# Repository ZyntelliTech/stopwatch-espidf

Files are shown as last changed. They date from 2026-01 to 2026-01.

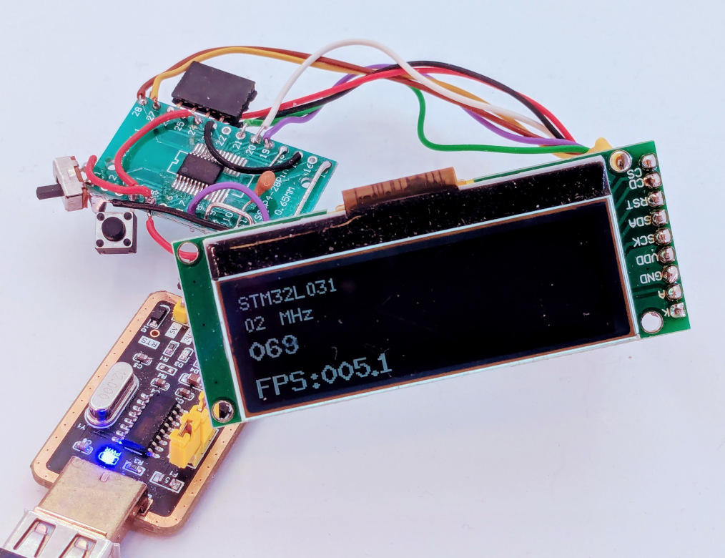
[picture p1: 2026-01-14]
Firmware/components/u8g2/sys/arm/stm32l031x4/u8g2_dma_spi_2mhz/stm32l031_wired.jpg

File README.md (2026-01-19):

# Stopwatch ESP-IDF Project

This project implements a stopwatch using ESP-IDF on an ESP32 microcontroller with an OLED display.
## Hardware Architecture
The ESP32-S3 GPIO pins have been assigned as follows: 

GPIO12 ------> SCL <br>
GPIO11 ------> SDA <br> 
GPIO10 ------> CS <br>
GPIO9  ------> DC<br>
GPIO8  ------> RES<br>

GPIO5  ------> left button: Start/Stop <br>
GPIOP6 ------> middle button: lapping/page navigation <br>
GPIO7  ------> right button: reset<br>

You can check the details in the schematic.

### How to order prototypes in JLCPCB
- Go to jlcpcb.com
- Click "Order now"
- Click "Add Gerber file" and upload /Hardware/Gerber_xxxxxxx.zip file
- Select the PCB Qty
- Enable the PCB Assembly
- Choose the Standard and Top Side assembly
- Click the NEXT button in the right panel. You will go to the next page
- Add the BOM and CPL(Pick-and-Place) files from hardware directory
- You can check the component stocks in the list
- In the Component Placements, you can check the assembled board.
- You can check the price in the Quote & Order page and save to cart

## Firmware Development

### Prerequisites

- [Visual Studio Code](https://code.visualstudio.com/)
- ESP32 development board (e.g., ESP32-S3)
- USB cable for flashing

### Installing ESP-IDF in VS Code

Follow these steps to set up the ESP-IDF development environment in Visual Studio Code. [Refer to this link.](https://www.youtube.com/watch?v=D0fRc4XHBNk) 

### 1. Install Visual Studio Code
If you haven't already, download and install VS Code from the official website.

### 2. Install the ESP-IDF Extension
1. Open VS Code.
2. Go to the Extensions view by clicking on the Extensions icon in the Activity Bar on the side of the window (or press `Ctrl+Shift+X`).
3. Search for "ESP-IDF".
4. Find the extension published by "Espressif Systems" and click "Install".

### 3. Open the Project
1. Open VS Code.
2. Select "File" > "Open Folder" and navigate to the `stopwatch-espidf/Firmware` directory.

### 4. Build and Flash the Project
1. In VS Code, open the Command Palette (`Ctrl+Shift+P`).
2. Type "ESP-IDF: Open ESP-IDF Terminal" and click it
3. Run "idf.py build".
4. Connect your ESP32 board via USB.
5. Run "idf.py flash monitor" to flash the firmware.
6. Optionally, run "idf.py -p COM[X] flash monitor" if the COM port is not automatically selected

## Project Structure

- `Firmware/`: Contains the ESP-IDF project files.
- `Firmware/main/`: Source code for the stopwatch application.
- `Firmware/components/`: Additional components like u8g2 for OLED display.
- `images/`: Project images like testing board diagram

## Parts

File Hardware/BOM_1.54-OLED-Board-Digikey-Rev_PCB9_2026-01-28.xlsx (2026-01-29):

No. | Quantity | Comment | Designator | Footprint | Value | Manufacturer Part | Manufacturer | Supplier Part | Supplier | LCSC Stock | LCSC Price | JLCPCB Stock | JLCPCB Price
1 | 1 | 2.2uF | C1 | C0201 | 2.2uF | CL03A225MP3CRNC | SAMSUNG(三星) | C318539 | LCSC |  |  | 319386 | 0.0011
2 | 8 | 10uF | C2,C4,C6,C7,C11,C12,C14,C18 | C0402 | 10uF | CL05A106MP5NUNC | SAMSUNG(三星) | C315248 | LCSC |  |  | 5447049 | 0.0013
3 | 6 | 100nF | C3,C5,C9,C10,C13,C16 | C0201 | 100nF | GRM033R61A104KE15D | muRata(村田) | C76934 | LCSC |  |  | 5065496 | 0.0002
4 | 1 | 1uF | C8 | C0201 | 1uF | HGC0201R5105K100NTCJ | Chinocera(华瓷) | C7432760 | LCSC |  |  | 51579 | 0.0015
5 | 1 | 22pF | C15 | C0201 | 22pF | CC0201JRNPO8BN220 | YAGEO(国巨) | C526934 | LCSC |  |  | 7062 | 0.0002
6 | 2 | 100nF | C17,C20 | C0201 | 100nF | CC0201KRX5R8BB104 | YAGEO(国巨) | C718252 | LCSC |  |  | 479402 | 0.0006
7 | 2 | 4.7uF | C19,C21 | C0603 | 4.7uF | GRM188R61E475KE11D | muRata(村田) | C90057 | LCSC |  |  | 348010 | 0.0037
8 | 1 | A1251WV-2P | CN1 | CONN-TH_2P-P1.25_A1251WV-2P |  | A1251WV-2P | CJT(长江连接器) | C5333427 | LCSC |  |  | 16958 | 0.0073
9 | 1 | LESD8LH5.0CT5G | D1 | SOD-882_L1.0-W0.6-BI |  | LESD8LH5.0CT5G | LRC(乐山无线电) | C172420 | LCSC |  |  | 13267 | 0.0023
10 | 2 | 1N5819WS | D2,D3 | SOD-323_L1.8-W1.3-LS2.5-RD |  | 1N5819WS | Hottech(合科泰) | C191023 | LCSC |  |  | 3408966 | 0.0012
11 | 1 | PM254V-11-06-H85 | H1 | HDR-TH_6P-P2.54-V-F |  | PM254V-11-06-H85 | XFCN(兴飞) | C2832269 | LCSC |  |  | 34883 | 0.0106
12 | 1 | 10uH | L1 | IND-SMD_L2.5-W2.0_MHCD252012B-2R2M-A8L | 10uH | DFE252012F-100M=P2 | muRata(村田) | C703141 | LCSC |  |  | 6823 | 0.0217
13 | 1 | HC-FPC-05-09-24RLTAG | P1 | FPC-SMD_24P-P0.50_HC-FPC-05-09-24RLTAG |  | HC-FPC-05-09-24RLTAG | HCTL(华灿天禄) | C5213757 | LCSC |  |  | 39879 | 0.0234
14 | 1 | AO3401A | Q1 | SOT-23_L2.9-W1.3-P1.90-LS2.4-BR |  | AO3401A | UMW(友台半导体) | C347476 | LCSC |  |  | 966091 | 0.0044
15 | 1 | SS8550W | Q2 | SOT-323-3_L2.0-W1.3-P1.30-LS2.3-BR |  | SS8550W | TWGMC(迪嘉) | C5189253 | LCSC |  |  | 17081 | 0.0028
16 | 2 | 5.1kΩ | R1,R2 | R0201 | 5.1kΩ | 0201WMF5101TEE | UNI-ROYAL(厚声) | C270344 | LCSC |  |  | 295343 | 0.0002
17 | 3 | 100kΩ | R3,R13,R16 | R0201 | 100kΩ | 0201WMF1003TEE | UNI-ROYAL(厚声) | C270364 | LCSC |  |  | 2234534 | 0.0002
18 | 4 | 10kΩ | R4,R9,R10,R12 | R0201 | 10kΩ | 0201WMF1002TEE | UNI-ROYAL(厚声) | C473048 | LCSC |  |  | 1248891 | 0.0002
19 | 1 | 1kΩ | R5 | R0402 | 1kΩ | RMC04021K5%N | Tyohm(幸亚电阻) | C270121 | LCSC |  |  | 4188 | 0.0003
20 | 1 | 2kΩ | R6 | R0201 | 2kΩ | 0201WMF2001TEE | UNI-ROYAL(厚声) | C270358 | LCSC |  |  | 728999 | 0.0002
21 | 2 | 470kΩ | R7,R8 | R0201 | 470kΩ | 0201WMF4703TEE | UNI-ROYAL(厚声) | C473560 | LCSC |  |  | 2133 | 0.0002
22 | 1 | 470Ω | R11 | R0201 | 470Ω | 0201WMF4700TEE | UNI-ROYAL(厚声) | C473464 | LCSC |  |  | 91499 | 0.0002
23 | 1 | 887kΩ | R14 | R0201 | 887kΩ | RC0201FR-07887KL | YAGEO(国巨) | C474853 | LCSC |  |  | 4670 | 0.0002
24 | 3 | 4.7kΩ | R15,R17,R18 | R0201 | 4.7kΩ | 0201WMF4701TEE | UNI-ROYAL(厚声) | C270346 | LCSC |  |  | 345024 | 0.0002
25 | 1 | 910kΩ | R19 | R0201 | 910kΩ | RC0201FR-07910KL | YAGEO(国巨) | C295818 | LCSC |  |  | 7664 | 0.0002
26 | 3 | HX-3x6x3.5-CA-0.6-2.5N | SW1,SW2,SW3 | SW-SMD_HX-3X6X3.5-CA-0.6-2.5N |  | HX-3x6x3.5-CA-0.6-2.5N | hanxia(韩下) | C49234146 | LCSC |  |  | 18106 | 0.0033
27 | 1 | 2.4GHz | U1 | BULETM-SMD_ESP32-S3-MINI-1-N8 | 2.4GHz | ESP32-S3-MINI-1-N8 | ESPRESSIF(乐鑫) | C2913206 | LCSC |  |  | 10861 | 0.6671
28 | 1 | SPX3819M5-L-3-3 | U2 | SOT-23-5_L3.0-W1.6-P0.95-LS2.8-BR |  | SPX3819M5-L-3-3 | TECH PUBLIC(台舟) | C20617301 | LCSC |  |  | 42998 | 0.0151
29 | 1 | GT-USB-7040C | U3 | USB-C-SMD_GT-USB-7040C |  | GT-USB-7040C | G-Switch(品赞) | C5447091 | LCSC |  |  | 4656 | 0.0411
30 | 1 | XL-1005UOC | U4 | LED0402-RD_ORANGE |  | XL-1005UOC | XINGLIGHT(成兴光) | C965791 | LCSC |  |  | 54064 | 0.002
31 | 1 | TP4054 | U5 | TSOT-23-5_L2.9-W1.6-P0.95-LS2.8-BR |  | TP4054 | UMW(友台半导体) | C668215 | LCSC |  |  | 162439 | 0.0048
33 | 1 | W25Q128JVPIQ | U7 | WSON-8_L6.0-W5.0-P1.27-BL-EP |  | W25Q128JVPIQ | Winbond(华邦) | C190862 | LCSC |  |  | 8996 | 0.3958
34 | 1 | AP3012KTR-G1 | U8 | TSOT-23-5_L2.9-W1.6-P0.95-LS2.8-BL |  | AP3012KTR-G1 | DIODES(美台) | C102618 | LCSC |  |  | 4829 | 0.0155

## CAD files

Firmware/components/u8g2/sys/arduino/u8g2_full_buffer/SwitchBox/board.dxf
60
40
52
8
24
80
30
32
25
100
190
4
12
6
14

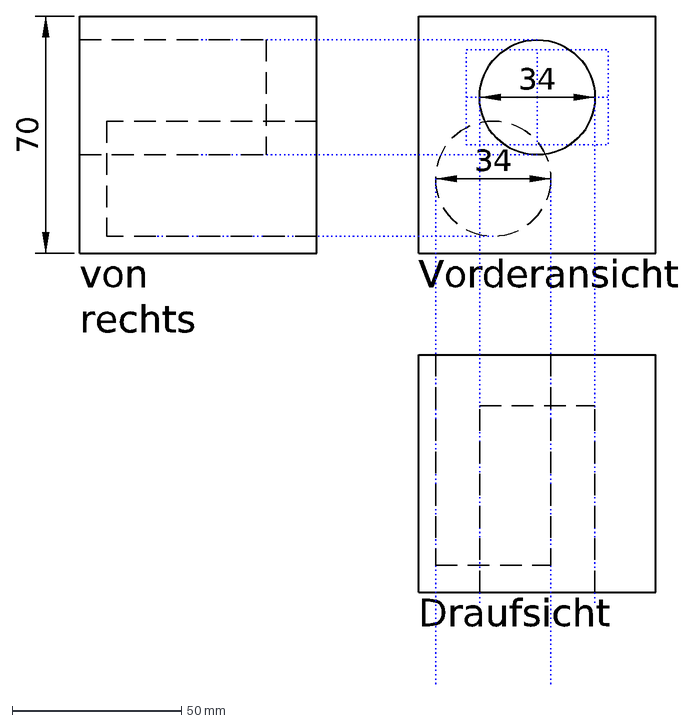
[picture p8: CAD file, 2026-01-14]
Firmware/components/u8g2/sys/arm/stm32l031x6/clock_cube.dxf
Draufsicht
Vorderansicht
von rechts
70
34

Firmware/components/u8g2/sys/arm/stm32l031x6/clock.dxf
65
32
28
16
Draufsicht
Vorderansicht
von unten
von rechts
von links
14
6
45
60
30
20
8
35
75
55
10
12

Firmware/components/u8g2/sys/arm/stm32l031x6/clock_2.dxf
65
Draufsicht
Vorderansicht
von unten
von rechts
von links
14
30
32
35
75
55
10
12
16
11
22
34
28
29
18
93
19
43
15
68
60
57
150
Holzbohrer: 2.5, 8, 10, 12, 16, 32mm
8
7
6
2.5mm

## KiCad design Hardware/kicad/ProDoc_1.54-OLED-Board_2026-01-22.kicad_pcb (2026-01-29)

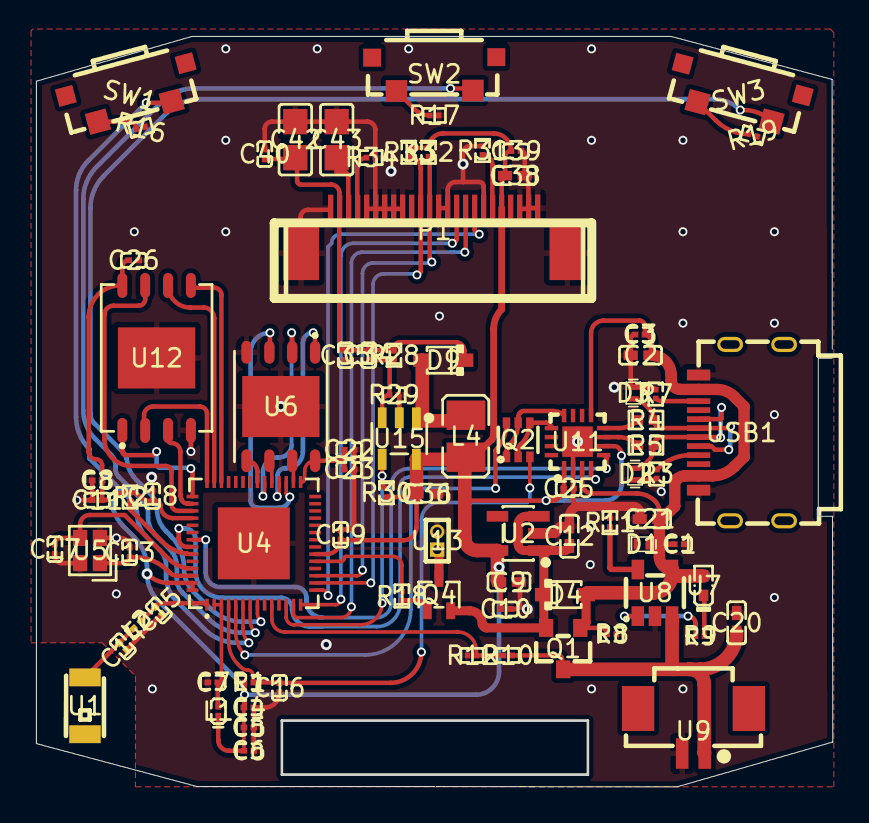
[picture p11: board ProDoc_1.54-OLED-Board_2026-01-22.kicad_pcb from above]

Board: 2 copper layers, 44.2 x 41.7 mm, 83 parts (0 on the bottom side), 61 nets.

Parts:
C1: 2.2uF; C0201
C2, C9, C12, C20, C21, C36, C38: 10uF; C0402
C3, C4, C6, C7, C8, C10, C11, C16, C18, C19, C22, C25, C26, C35, C39, C40: 100nF; C0201
C5, C23: 1uF; C0201
C13, C17: 15pF; C0201
C14: 1.8pF; C0201
C15: 1.2pF; C0201
C34: 22pF; C0201
C42, C43: 10uF; C0805
D1, D2, D3: LESD8LH5.0CT5G; SOD-882_L1.0-W0.6-BI
D4, D9: 1N5819WS_C191023; SOD-323_L1.8-W1.3-LS2.5-RD
L1: 2nH; L0201-RD
L2: 2.4nH; L0201
L4: 10uH; L1008
P1: FPC 0.5MM 24P Pull type H2.0mm Pick up; FPC-SMD_24P-L17.5-W5.4-P0.50
Q1: AO3401A_C347476; SOT-23_L2.9-W1.3-P1.90-LS2.4-BR
Q2: UMH3N; SC-70-6_L2.2-W1.3-P0.65-LS2.1-BR
Q4: SS8550W; SOT-323-3_L2.0-W1.3-P1.30-LS2.3-BR
R1, R2, R16, R17, R19: 10kΩ; R0201
R3, R7: 5.1kΩ; R0201
R4, R5: 0Ω; R0402
R8, R29, R30: 100kΩ; R0201
R9: 1kΩ; R0201
R10, R12: 470kΩ; R0201
R11: 2kΩ; R0201
R18: 470Ω; R0201
R28: 887kΩ; R0201
R31, R32, R33: 4.7kΩ; R0201
R34: 910kΩ; R0201
SW1, SW2, SW3: TS36CA-0.6 250gf 031; SW-SMD_SHOU_TS36CA-0.6
U1: ANT3216LL00R2400A; ANT-SMD_L3.2-W1.6
U2: SPX3819M5-L-3-3; SOT-23-5_L3.0-W1.6-P0.95-LS2.8-BR
U4: ESP32-S3R8; QFN-56_L7.0-W7.0-P0.40-TL-EP4.0
U5: 40MHz; CRYSTAL-SMD_4P-L2.0-W1.6-BL
U6: W25Q128JVPIQ; WSON-8_L6.0-W5.0-P1.27-BL-EP
U7: XL-1005UOC; LED0402-RD_ORANGE
U8: TP4054_C668215; TSOT-23-5_L2.9-W1.6-P0.95-LS2.8-BR
U9: ZX-MX1.25-2PWT; CONN-SMD_2P-P1.25_MEGASTAR_ZX-MX1.25-2PWT
U11: CH343P; TQFN-16_L3.0-W3.0-P0.50-BL-EP1.7
U12: W25N01GVZEIG; WSON-8_L8.0-W6.10-P1.27-BL-EP
U13: HX PZ1.0-1x2P ZZ; HDR-TH_2P-P1.00-V-M
U15: TPS61040DBVR; SOT-23-5_L3.0-W1.7-P0.95-LS2.8-BL
USB1: HYCW412-USBC16-065B; USB-C-SMD_HYCW412-USBC16-065B

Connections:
5V: C1.1, C2.2, C3.2, C21.2, D1.1, D4.2, Q1.1, R8.1, U7.2, U8.4, U11.3, U11.9, USB1.A4B9, USB1.B4A9
12V: C34.2, C35.2, C40.2, C42.2, D9.1, P1.23, R28.2
$1N9431: C15.2, L2.2, U4.1
$1N9432: C7.2, L1.2, U4.2, U4.3
$1N9438: C13.1, U4.54, U5.1
$1N9473: C17.2, U4.53, U5.3
$1N9512: R9.1, U7.1
$1N9513: R9.2, U8.1
$1N9514: R11.1, U8.5
$1N9533: R16.1, SW1.1
$1N9534: R17.1, SW2.1
$1N9535: R19.1, SW3.1
$1N9548: Q4.1, R18.2
$1N9549: Q4.3, U13.1
$1N9587: C14.2, L2.1, U1.2
$1N9591: R7.2, USB1.B5
$1N9592: R3.1, USB1.A5
$1N9604: P1.6, R31.2
$1N9614: D9.2, L4.2, U15.1
$1N9616: C34.1, R28.1, R29.2, U15.3
$1N9620: P1.21, R34.2
$1N9621: C43.2, P1.22
+3V3: C4.2, C5.2, C6.2, C8.2, C9.2, C10.2, C11.2, C18.2, C19.2, C25.2, C26.2, C36.2, C38.1, C39.1, L1.1, L4.1, P1.5, R1.2, R2.2, R30.2, R32.1, R33.1, U2.5, U4.20, U4.46, U4.55, U4.56, U11.1, U11.6, U12.8, U15.5
BAT_ADC: R10.1, R12.2, U4.10
BUZZER: R18.1, U4.19
CHIP_EN: C16.2, Q2.3, R1.1, U4.4
CLK: P1.13, R32.2, U4.17
CS: P1.8, U4.15
D+: R5.1, U11.7
D-: R4.1, U11.8
DC: P1.10, U4.14
DIN: P1.14, R33.2, U4.16
DTR: Q2.1, Q2.5, U11.12
EN: R30.1, U4.12, U15.4
FCLK: U4.41, U12.6
FCS: U4.43, U12.1
FDI: U4.40, U12.5
FDO: U4.42, U12.2
FHOLD: U4.45, U12.7
FWP: U4.44, U12.3
GND: C1.2, C2.1, C3.1, C4.1, C5.1, C6.1, C7.1, C8.1, C9.1, C10.1, C11.1, C12.1, C13.2, C14.1, C15.1, C16.1, C17.1, C18.1, C19.1, C20.1, C21.1, C22.1, C23.1, C25.1, C26.1, C35.1, C36.1, C38.2, C39.2, C40.1, C42.1, C43.1, D1.2, D2.2, D3.1, P1.1, P1.2, P1.3, P1.7, P1.11, P1.12, P1.16, P1.17, P1.18, P1.19, P1.20, P1.24, P1.25, P1.26, R3.2, R7.1, R8.2, R11.2, R12.1, R16.2, R17.2, R19.2, R29.1, R31.1, R34.1, U2.2, U4.57, U5.2, U5.4, U6.4, U6.9, U8.2, U9.2, U11.2, U11.17, U12.4, U12.9, U13.2, U15.2, USB1.A1B12, USB1.B1A12
IO0: Q2.6, U4.5
IO45: R2.1, U4.51
KEY1: SW1.2, U4.6
KEY2: SW2.2, U4.7
KEY3: SW3.2, U4.8
RES: P1.9, U4.13
RTS: Q2.2, Q2.4, U11.13
SPICLK: U4.33, U6.6
SPICS0: U4.32, U6.1
SPID: U4.35, U6.5
SPIHD: U4.30, U6.7
SPIQ: U4.34, U6.2
SPIWP: U4.31, U6.3
U0RXD: U4.50, U11.4
U0TXD: U4.49, U11.5
USB+: D2.1, R5.2, USB1.A6, USB1.B6
USB-: D3.2, R4.2, USB1.A7, USB1.B7
VBAT: C20.2, Q1.3, R10.2, U8.3, U9.1
VDD_SPI: C22.2, C23.2, U4.29, U6.8
VSYS: C12.2, D4.1, Q1.2, Q4.2, U2.1, U2.3

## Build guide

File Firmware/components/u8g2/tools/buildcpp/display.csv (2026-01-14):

# 1. device name
# 2. pinset
# 3. constructor name w/o prefix
u8x8_d_ssd1306_128x64_noname | 4WSWSPI | SSD1306_128X64_4W_SW_SPI
u8x8_d_ssd1306_128x64_noname | 4WHWSPI | SSD1306_128X64_4W_HW_SPI
u8x8_d_ssd1306_128x64_noname | 3WSWSPI | SSD1306_128X64_3W_SW_SPI
u8x8_d_ssd1306_128x64_noname | SSDSWI2C | SSD1306_128X64_SW_I2C
u8x8_d_ssd1306_128x64_noname | 6800 | SSD1306_128X64_6800
u8x8_d_ssd1306_128x64_noname | 8080 | SSD1306_128X64_8080

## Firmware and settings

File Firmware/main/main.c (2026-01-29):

#include <stdio.h>
#include <string.h>
#include "freertos/FreeRTOS.h"
#include "freertos/task.h"
#include "sdkconfig.h"
#include "esp_log.h"
#include "rtc_timer.h"
#include "oled.h"
#include "stopwatch.h"
#include "driver/gpio.h"

#define DEBOUNCE_MS  10
typedef struct {
    char name[32];
    char type[32];
    char lane_count[2];
    char watch_number[2];
} player_t;

player_t player;

typedef enum {
    STOPWATCH_PAGE = 0,
    SWIMMING_PAGE,
    CONFIRM_PAGE,
    HEADTIMER_PAGE
} page_state_t;

static const char *TAG = "main";
static char time_buffer[16] = {0};
uint8_t page_index = STOPWATCH_PAGE;

#define BTN_START_STOP   GPIO_NUM_5
#define BTN_RECALL       GPIO_NUM_6
#define BTN_LAP_RESET    GPIO_NUM_7

static void buttons_init(void)
{
    gpio_config_t io_conf = {
        .pin_bit_mask =
            (1ULL << BTN_START_STOP) |
            (1ULL << BTN_RECALL) |
            (1ULL << BTN_LAP_RESET),
        .mode = GPIO_MODE_INPUT,
        .pull_up_en = GPIO_PULLUP_ENABLE,
        .pull_down_en = GPIO_PULLDOWN_DISABLE,
        .intr_type = GPIO_INTR_DISABLE
    };
    gpio_config(&io_conf);
}

/* 1-second periodic task */
static void one_second_task(void *arg)
{
    TickType_t last_wake_time = xTaskGetTickCount();

    while (1)
    {
        /* Runs exactly every 1 second */
        vTaskDelayUntil(&last_wake_time, pdMS_TO_TICKS(1000));

        rtc_get_time(time_buffer, sizeof(time_buffer));
    }
}

void app_main(void)
{
    uint32_t last_state = 0xFFFFFFFF;
    uint32_t stable_state = last_state;
    bool stopwatch_running = false;

    ESP_LOGI(TAG, "Initializing OLED display");
    oled_init();
    buttons_init();

    rtc_set_time(2026, 1, 6, 15, 0, 0);

    ESP_LOGI(TAG, "All done!");
    
    char buf[16];   // ✅ RAM buffer
    char lap_buf[16];
    char split_buf[16];
    char lap_count_str[4];
    uint8_t lap_count = 0;
    
    memset(buf, '0', sizeof(buf));
    memset(lap_buf, '0', sizeof(lap_buf));
    memset(split_buf, '0', sizeof(split_buf));
    memset(lap_count_str, '0', sizeof(lap_count_str));

    while (1)
    {  
        uint32_t state =
            (gpio_get_level(BTN_START_STOP) << 0) |
            (gpio_get_level(BTN_RECALL)     << 1) |
            (gpio_get_level(BTN_LAP_RESET)  << 2);
        
        if (state != last_state) {
            vTaskDelay(pdMS_TO_TICKS(DEBOUNCE_MS));
            last_state = state;
            continue;
        }
        if (state != stable_state) {
            stable_state = state;

            //Active Low buttons
            if (!(state & (1 << 0))) {  // START/STOP - Right Button
                if ((page_index != CONFIRM_PAGE)){
                    if(get_stopwatch_state() == 0) {
                        stopwatch_start();
                    } else {
                        stopwatch_stop();
                    }
                } else {
                    page_index = SWIMMING_PAGE;
                    strcpy(player.name, "");
                    strcpy(player.type, "FREESTYLE");  
                    strcpy(player.lane_count, "4");
                    strcpy(player.watch_number, "1");     
                }
            }
            if (!(state & (1 << 1))) {  // LAP / PAGE SWITCH - Middle Button
                if (get_stopwatch_state()) {
                    if ((page_index == STOPWATCH_PAGE) && stopwatch_lap()) {
                        lap_entry_t lap;
                        uint8_t idx = stopwatch_get_lap_count() - 1;
                        stopwatch_get_lap(idx, &lap);
                        stopwatch_get_lap_str(idx, lap_buf, sizeof(lap_buf));
                        stopwatch_get_split_str(idx, split_buf, sizeof(split_buf));
                        snprintf(lap_count_str, sizeof(lap_count_str), "%02u", idx + 1);
                    }

                } else {
                    if (page_index == SWIMMING_PAGE) {
                        page_index = STOPWATCH_PAGE;
                    }
                    else if (page_index == STOPWATCH_PAGE) {
                        page_index = SWIMMING_PAGE;
                    }
                }
            }
            if (!(state & (1 << 2))) {   // RESET - Left Button
                if (stopwatch_is_initialized()){
                    if (page_index == SWIMMING_PAGE) {
                        page_index = CONFIRM_PAGE;
                    } else if (page_index == CONFIRM_PAGE) {
                        page_index = SWIMMING_PAGE;
                        strcpy(player.name, "JOHN DOE");
                        strcpy(player.type, "FREESTYLE");  
                        strcpy(player.lane_count, "4");
                        strcpy(player.watch_number, "1");            
                    }
                } else {
                    if ((get_stopwatch_state() == 0)) {
                        stopwatch_reset();
                        memset(buf, '0', sizeof(buf));
                        memset(lap_buf, '0', sizeof(lap_buf));
                        memset(split_buf, '0', sizeof(split_buf));
                        memset(lap_count_str, '0', sizeof(lap_count_str));
                    }
                }
                
            }
        }

        stopwatch_get_str_10ms(buf, sizeof(buf));

        switch (page_index)
        {
            case STOPWATCH_PAGE:
            oled_draw_stopwatch(buf, lap_buf, split_buf, lap_count_str);
            break;
        case SWIMMING_PAGE:
            oled_draw_swimming_watch(buf, player.name, player.type, player.lane_count, player.watch_number, true);
            break;
        case HEADTIMER_PAGE:
            oled_draw_headtimer_watch(buf, true);
            break;
        case CONFIRM_PAGE:
            oled_draw_confirm_watch();
            break;
        default:
            break;
        }
        vTaskDelay(pdMS_TO_TICKS(1));
    }
}

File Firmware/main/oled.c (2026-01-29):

#include "oled.h"
#include <driver/gpio.h>
#include <driver/spi_master.h>
#include <esp_log.h>
#include <freertos/FreeRTOS.h>
#include <freertos/task.h>
#include <stdio.h>
#include <string.h>
#include <u8g2.h>
#include "u8g2_esp32_hal.h"

// CLK - GPIO12
#define PIN_CLK 12

// MOSI - GPIO 11
#define PIN_MOSI 11

// RESET - GPIO 8
#define PIN_RESET 8

// DC - GPIO 9
#define PIN_DC 9

// CS - GPIO 10
#define PIN_CS 10

static const char *TAG = "OLED";

static u8g2_t u8g2;

/* Stopwatch Assets*/
static const uint8_t image_battery_full_bits[] = {0x00,0x00,0x00,0xf0,0xff,0x7f,0x08,0x00,0x80,0x68,0xdb,0xb6,0x6e,0xdb,0xb6,0x61,0xdb,0xb6,0x61,0xdb,0xb6,0x61,0xdb,0xb6,0x61,0xdb,0xb6,0x61,0xdb,0xb6,0x6e,0xdb,0xb6,0x68,0xdb,0xb6,0x08,0x00,0x80,0xf0,0xff,0x7f,0x00,0x00,0x00,0x00,0x00,0x00};
static const uint8_t image_battery_17_bits[] = {0x00,0x00,0x00,0xf0,0xff,0x7f,0x08,0x00,0x80,0x08,0x00,0xb0,0x0e,0x00,0xb0,0x01,0x00,0xb0,0x01,0x00,0xb0,0x01,0x00,0xb0,0x01,0x00,0xb0,0x01,0x00,0xb0,0x0e,0x00,0xb0,0x08,0x00,0xb0,0x08,0x00,0x80,0xf0,0xff,0x7f,0x00,0x00,0x00,0x00,0x00,0x00};
static const uint8_t image_battery_33_bits[] = {0x00,0x00,0x00,0xf0,0xff,0x7f,0x08,0x00,0x80,0x08,0x00,0xb6,0x0e,0x00,0xb6,0x01,0x00,0xb6,0x01,0x00,0xb6,0x01,0x00,0xb6,0x01,0x00,0xb6,0x01,0x00,0xb6,0x0e,0x00,0xb6,0x08,0x00,0xb6,0x08,0x00,0x80,0xf0,0xff,0x7f,0x00,0x00,0x00,0x00,0x00,0x00};
static const uint8_t image_battery_50_bits[] = {0x00,0x00,0x00,0xf0,0xff,0x7f,0x08,0x00,0x80,0x08,0xc0,0xb6,0x0e,0xc0,0xb6,0x01,0xc0,0xb6,0x01,0xc0,0xb6,0x01,0xc0,0xb6,0x01,0xc0,0xb6,0x01,0xc0,0xb6,0x0e,0xc0,0xb6,0x08,0xc0,0xb6,0x08,0x00,0x80,0xf0,0xff,0x7f,0x00,0x00,0x00,0x00,0x00,0x00};
static const uint8_t image_battery_67_bits[] = {0x00,0x00,0x00,0xf0,0xff,0x7f,0x08,0x00,0x80,0x08,0xd8,0xb6,0x0e,0xd8,0xb6,0x01,0xd8,0xb6,0x01,0xd8,0xb6,0x01,0xd8,0xb6,0x01,0xd8,0xb6,0x01,0xd8,0xb6,0x0e,0xd8,0xb6,0x08,0xd8,0xb6,0x08,0x00,0x80,0xf0,0xff,0x7f,0x00,0x00,0x00,0x00,0x00,0x00};
static const uint8_t image_battery_83_bits[] = {0x00,0x00,0x00,0xf0,0xff,0x7f,0x08,0x00,0x80,0x08,0xdb,0xb6,0x0e,0xdb,0xb6,0x01,0xdb,0xb6,0x01,0xdb,0xb6,0x01,0xdb,0xb6,0x01,0xdb,0xb6,0x01,0xdb,0xb6,0x0e,0xdb,0xb6,0x08,0xdb,0xb6,0x08,0x00,0x80,0xf0,0xff,0x7f,0x00,0x00,0x00,0x00,0x00,0x00};

static const uint8_t image_chrono_minute_colon_bits[] = {0x03,0x03,0x00,0x00,0x00,0x00,0x00,0x00,0x00,0x03,0x03};
static const uint8_t image_chrono_second_point_bits[] = {0x03,0x03};
static const uint8_t image_lap_string_bits[] = {0x03,0x30,0xfc,0x00,0x03,0x78,0xfc,0x01,0x03,0x78,0x0c,0x03,0x03,0xcc,0x0c,0x03,0x03,0xcc,0xfc,0x01,0x03,0x86,0xfd,0x00,0x03,0xfe,0x0d,0x00,0x03,0xfe,0x0d,0x00,0x03,0x86,0x0d,0x00,0xff,0x86,0x0d,0x00,0xff,0x86,0x0d,0x00};
static const uint8_t image_split_hour_colon_bits[] = {0x03,0x03,0x00,0x00,0x00,0x00,0x00,0x03,0x03};
static const uint8_t image_split_string_bits[] = {0x3c,0x7e,0x0c,0xf8,0xf7,0x0f,0x7e,0xfe,0x0c,0xf8,0xf7,0x0f,0xc3,0x86,0x0d,0xc0,0x80,0x01,0x03,0x86,0x0d,0xc0,0x80,0x01,0x3e,0xfe,0x0c,0xc0,0x80,0x01,0x7c,0x7e,0x0c,0xc0,0x80,0x01,0xe0,0x06,0x0c,0xc0,0x80,0x01,0xc3,0x06,0x0c,0xc0,0x80,0x01,0xc3,0x06,0x0c,0xc0,0x80,0x01,0x7e,0x06,0xfc,0xfb,0x87,0x01,0x3c,0x06,0xfc,0xfb,0x87,0x01};

static const uint8_t image_wifi_connected_bits[] = {0x00,0x70,0x00,0x70,0x00,0x70,0x00,0x70,0x00,0x77,0x00,0x77,0x00,0x77,0x00,0x77,0x70,0x77,0x70,0x77,0x70,0x77,0x70,0x77,0x77,0x77,0x77,0x77,0x77,0x77,0x00,0x00};
static const uint8_t image_wifi_not_connected_bits[] = {0x41,0x70,0x22,0x50,0x14,0x50,0x08,0x50,0x14,0x57,0x22,0x55,0x41,0x55,0x00,0x55,0x70,0x55,0x50,0x55,0x50,0x55,0x50,0x55,0x57,0x55,0x55,0x55,0x77,0x77,0x00,0x00};
static const uint8_t image_wifi_1_bar_bits[] = {0x00,0x70,0x00,0x50,0x00,0x50,0x00,0x50,0x00,0x57,0x00,0x55,0x00,0x55,0x00,0x55,0x70,0x55,0x50,0x55,0x50,0x55,0x50,0x55,0x57,0x55,0x57,0x55,0x77,0x77,0x00,0x00};
static const uint8_t image_wifi_2_bars_bits[] = {0x00,0x70,0x00,0x50,0x00,0x50,0x00,0x50,0x00,0x57,0x00,0x55,0x00,0x55,0x00,0x55,0x70,0x55,0x70,0x55,0x70,0x55,0x70,0x55,0x77,0x55,0x77,0x55,0x77,0x77,0x00,0x00};
static const uint8_t image_wifi_3_bars_bits[] = {0x00,0x70,0x00,0x50,0x00,0x50,0x00,0x50,0x00,0x57,0x00,0x57,0x00,0x57,0x00,0x57,0x70,0x57,0x70,0x57,0x70,0x57,0x70,0x57,0x77,0x57,0x77,0x57,0x77,0x77,0x00,0x00};

/* Swimming Watch Assets*/
static const uint8_t image_music_radio_streaming_bits[] = {0x00,0x00,0x00,0x00,0x00,0x00,0x04,0x40,0x00,0x02,0x80,0x00,0x12,0x90,0x00,0x09,0x21,0x01,0xa5,0x4b,0x01,0x95,0x52,0x01,0xa5,0x4b,0x01,0x09,0x21,0x01,0x12,0x90,0x00,0x02,0x80,0x00,0x04,0x40,0x00,0x00,0x00,0x00,0x00,0x00,0x00,0x00,0x00,0x00};

void draw_battery(u8g2_t *u8g2, uint8_t level) {
    u8g2_SetBitmapMode(u8g2, 1);
    // battery_full
    switch (level)
    {
    case BATTERY_FULL:
        /* code */
        u8g2_DrawXBM(u8g2, 0, 0, 24, 16, image_battery_full_bits);
        break;
    case BATTERY_83:
        u8g2_DrawXBM(u8g2, 0, 0, 24, 16, image_battery_83_bits);
        break;
    case BATTERY_67:
        u8g2_DrawXBM(u8g2, 0, 0, 24, 16, image_battery_67_bits);
        break;
    case BATTERY_50:
        u8g2_DrawXBM(u8g2, 0, 0, 24, 16, image_battery_50_bits);
        break;  
    case BATTERY_33:    
        u8g2_DrawXBM(u8g2, 0, 0, 24, 16, image_battery_33_bits);
        break;
    case BATTERY_17:
        u8g2_DrawXBM(u8g2, 0, 0, 24, 16, image_battery_17_bits);
        break;
    default:
        break;
    }
    
}

void draw_wfi_status(u8g2_t *u8g2, uint8_t signal) {
    u8g2_SetBitmapMode(u8g2, 1);
    // network_not_connected
    switch (signal)
    {
        case WIFI_NOT_CONNECTED:
            u8g2_DrawXBM(u8g2, 112, 0, 16, 16, image_wifi_not_connected_bits);
            break;
        case WIFI_1_BAR:
            u8g2_DrawXBM(u8g2, 112, 0, 16, 16, image_wifi_1_bar_bits);
            break;  
        case WIFI_2_BARS:  
            u8g2_DrawXBM(u8g2, 112, 0, 16, 16, image_wifi_2_bars_bits);
            break;
        case WIFI_3_BARS:   
            u8g2_DrawXBM(u8g2, 112, 0, 16, 16, image_wifi_3_bars_bits);
            break;
        case WiFI_CONNECTED:  
            u8g2_DrawXBM(u8g2, 112, 0, 16, 16, image_wifi_connected_bits);
            break;
    }
}
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

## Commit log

2026-01-14 Add custom components
    [board.dxf, clock.dxf, clock_2.dxf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]
2026-01-19 Add fabrication files
    [BOM_1.54-OLED-PCB.xlsx, PickAndPlace_1.54-OLED-PCB.xlsx, board.dxf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]
2026-01-29 update confirming page
    [BOM_1.54-OLED-PCB.xlsx, ProDoc_1.54-OLED-Board_2026-01-22.kicad_pcb, ProDoc_1.54-OLED-Board_2026-01-22.kicad_sch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]
2026-01-29 Update fabrication files
    [BOM_1.54-OLED-Board-Digikey-Rev_PCB9_2026-01-28.xlsx, BOM_1.54-OLED-PCB.xlsx, PickAndPlace_1.54-OLED-PCB.xlsx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]
